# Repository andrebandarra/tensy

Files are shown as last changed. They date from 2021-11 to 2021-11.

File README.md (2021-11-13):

<h1 align="center">Tensy</h1>

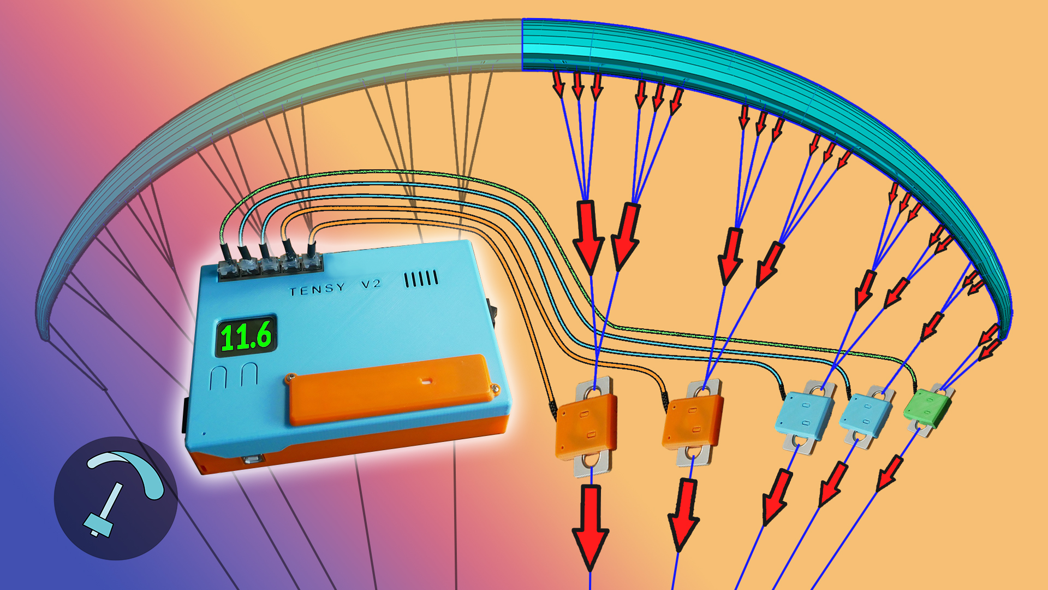
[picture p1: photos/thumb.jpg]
Table


https://www.youtube.com/watch?v=AOkSkCXVu8w --- https://andrebandarra.com/tensy
https://easyeda.com/Bandarra/line-tension-v2_copy

## Description
Wanting to measure a log loadsensor data from multiple paraglider lines in flight I've created Tensy.

It's based on an Arduino Due, the HX711 load sensor ADC and various periferals like an LCD, SD card module and various buttons.
Created a PCB for ease of wiring.

## Features
* Up to 13 load sensors
* Up to 50 kg range on each sensor
* +/- 50gram accuracy
* 10Hz sampling rate on all sensors in parallel
* 80Hz sampling rate on single sensors possible
* All data written to SD card
* LCD display for live data

[andrebandarra.com](https://andrebandarra.com/) --- [Youtube](https://www.youtube.com/channel/UCzYf1cmKwDMSiII9SSp6IJw) --- [Patreon](https://www.patreon.com/bandarra)

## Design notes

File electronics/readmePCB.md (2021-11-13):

editable pcb files on EasyEDA

https://easyeda.com/Bandarra/line-tension-v2_copy

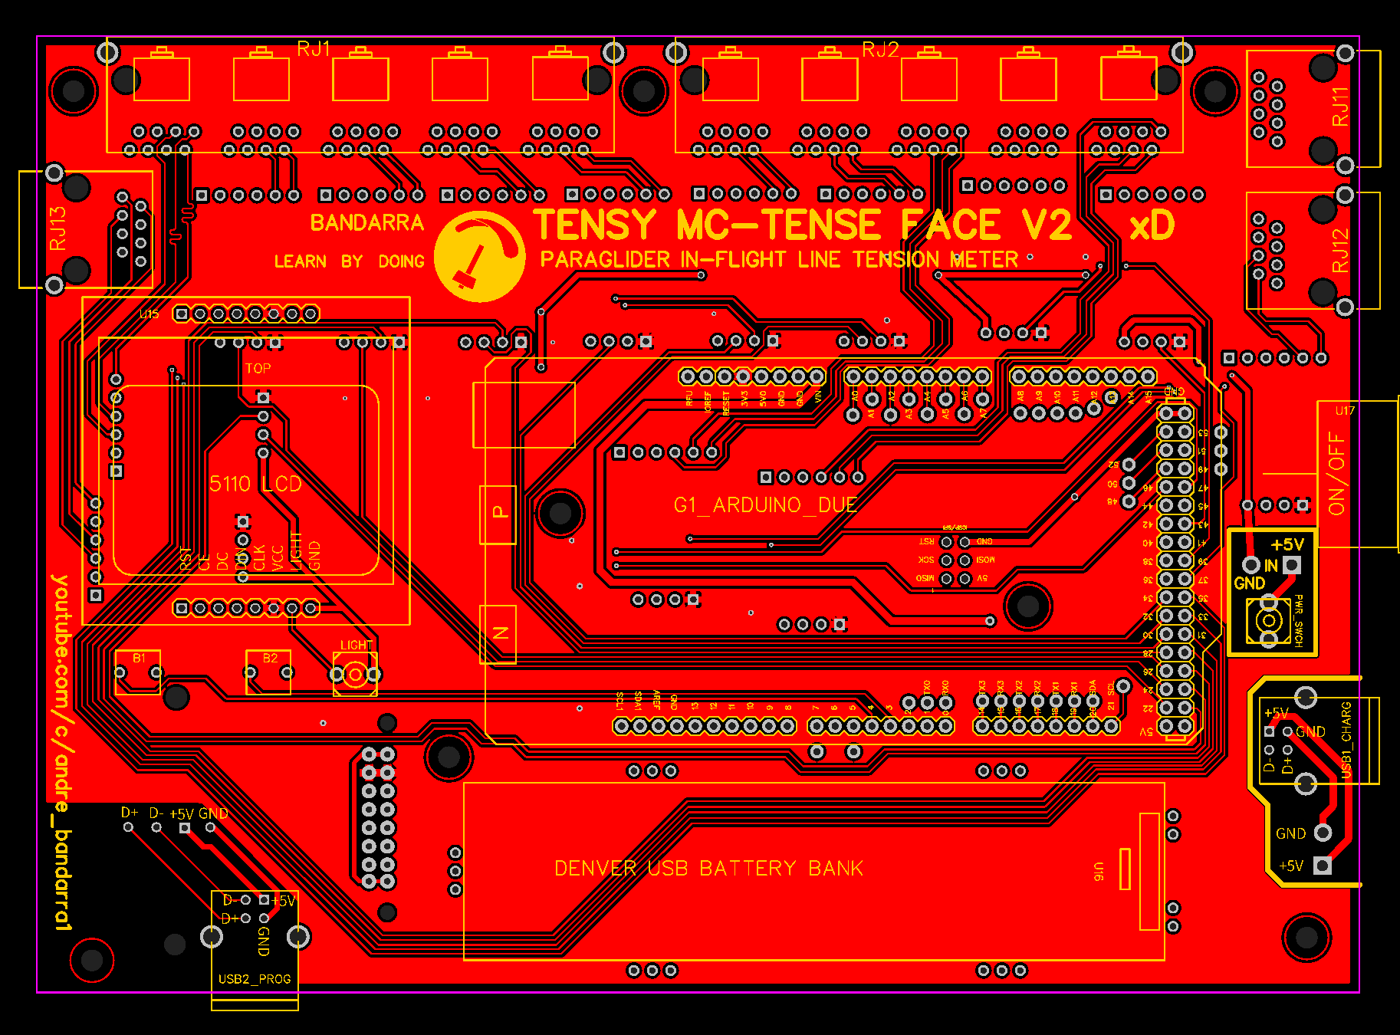
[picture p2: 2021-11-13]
electronics/schematics/PCB_Tensy Mc-Tense Face V2_20200204234458.png

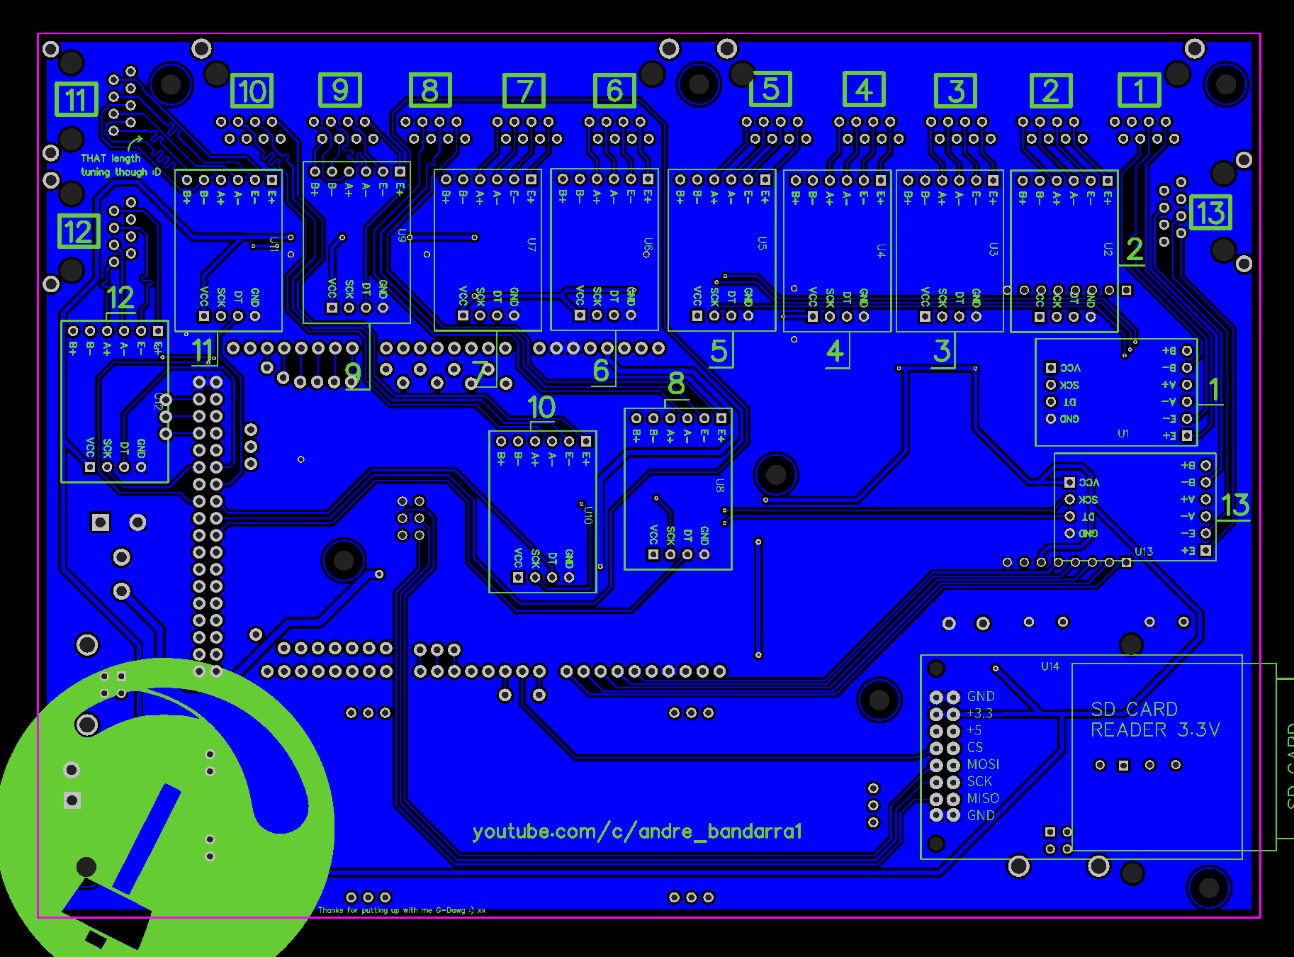
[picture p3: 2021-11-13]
electronics/schematics/PCB_Tensy Mc-Tense Face V2_20200204234511.png

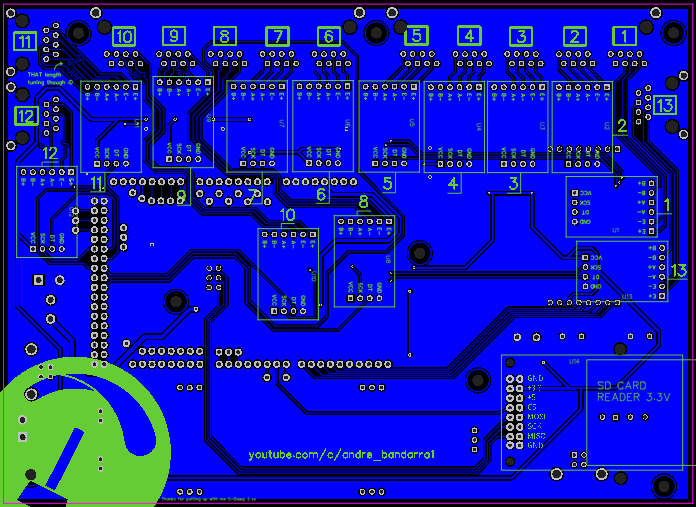
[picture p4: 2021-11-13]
cad/Tensy V2/easy eda original cad/PCB_Tensy Mc-Tense Face V2_20200315195208.png

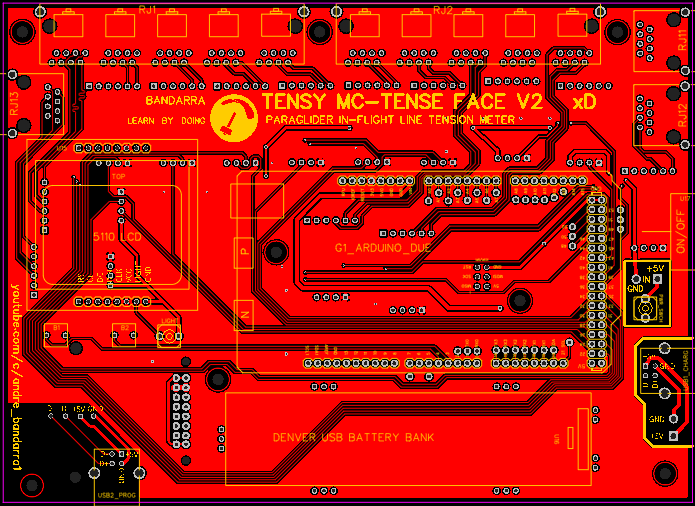
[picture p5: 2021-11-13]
cad/Tensy V2/easy eda original cad/PCB_Tensy Mc-Tense Face V2_20200315193410.png

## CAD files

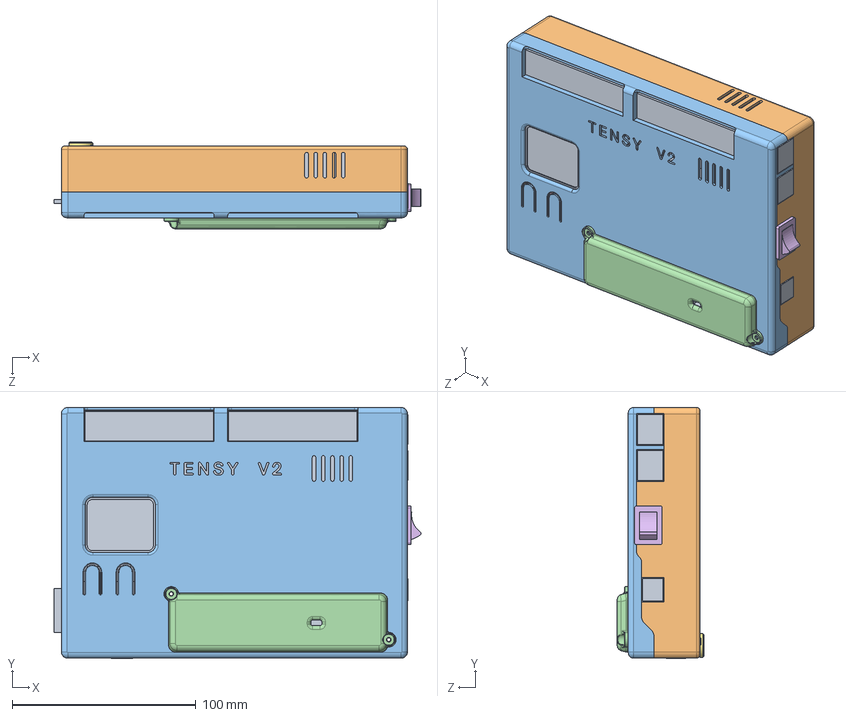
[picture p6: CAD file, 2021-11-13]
cad/Tensy V2/enclosure/Assy.SLDASM
199.9 x 136.8 x 47.2 mm
tensy final pcb
bottom
top
bat cover
sdspacer
power button
foot

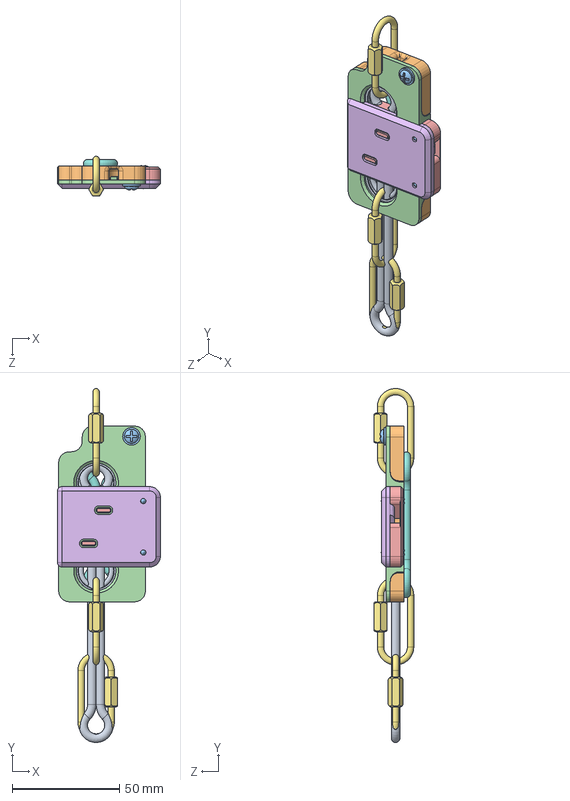
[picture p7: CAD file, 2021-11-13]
cad/sensor rigging assy/1 sensor assy.SLDASM
48.0 x 165.1 x 18.5 mm
load cell 50kg
black screw x 2
maillon35mm x 3
60mm spacer

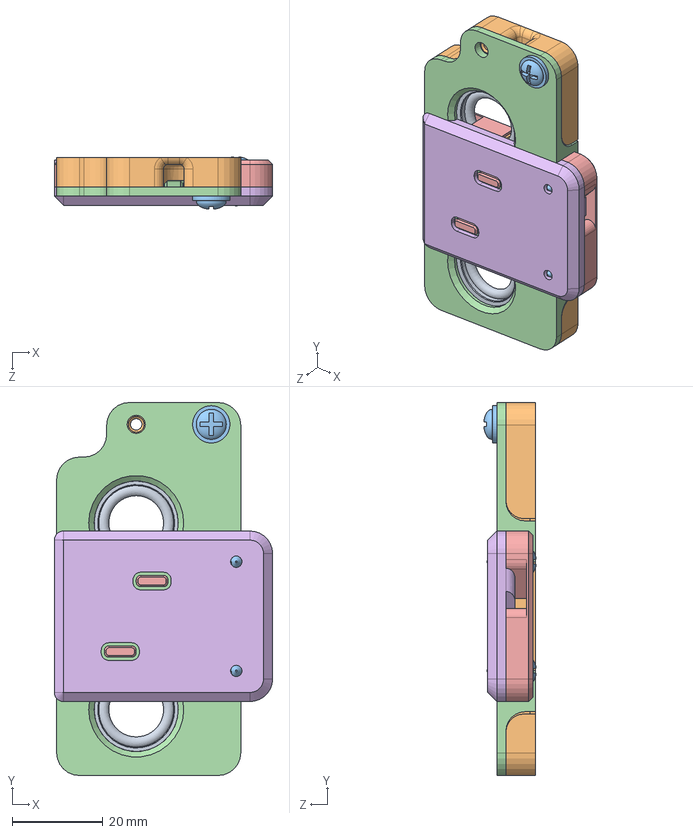
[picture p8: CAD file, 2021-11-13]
cad/Tensy V2/load cells/Assem1.SLDASM
48.0 x 82.0 x 11.5 mm
load cell 50kg
black screw x 2

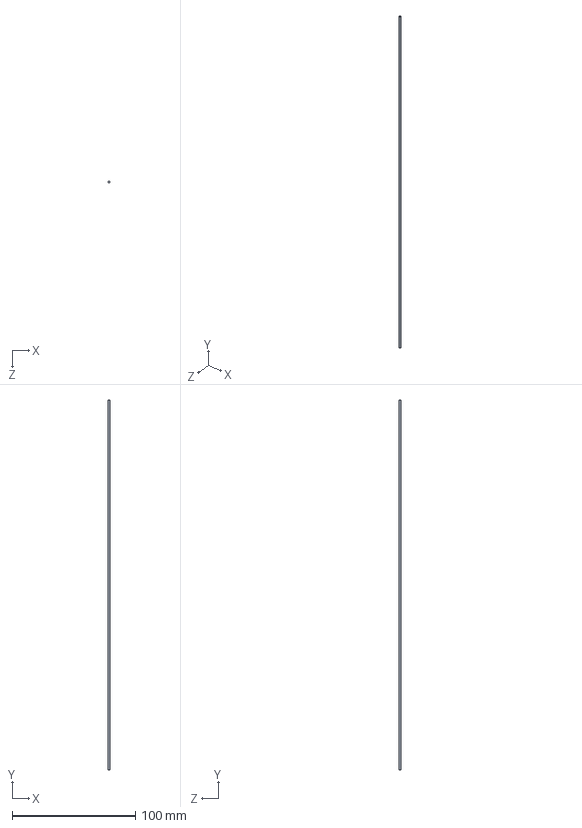
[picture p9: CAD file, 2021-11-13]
cad/riser set/1.5mm line.SLDPRT
1.50 x 300.0 x 1.50 mm

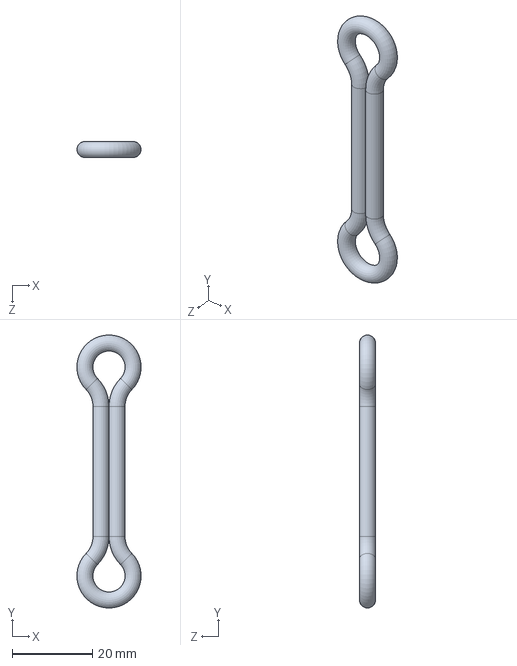
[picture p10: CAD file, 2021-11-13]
cad/sensor rigging assy/60mm spacer.SLDPRT
16.0 x 68.0 x 4.00 mm

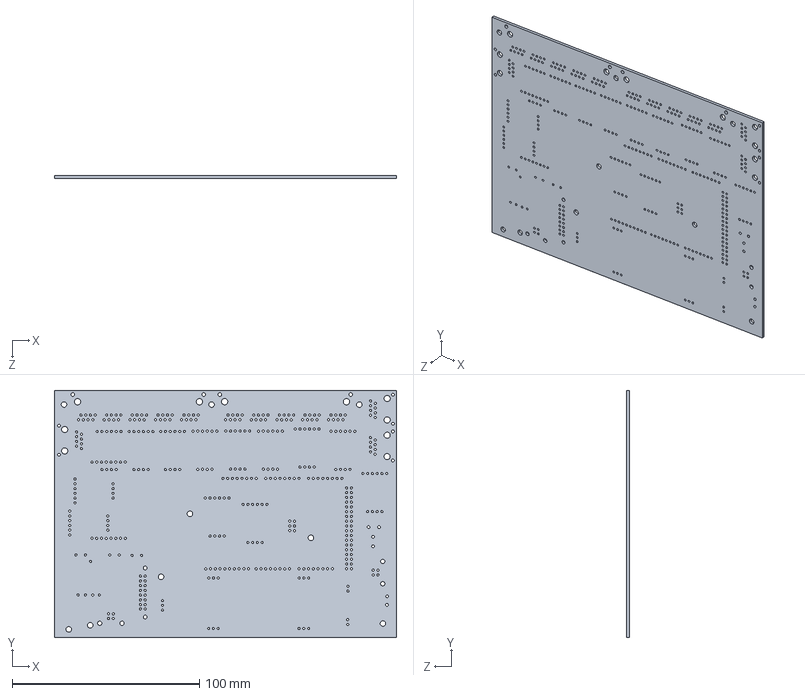
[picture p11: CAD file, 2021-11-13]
cad/Tensy V2/component test plate/test plate.SLDPRT
182.5 x 132.1 x 1.60 mm

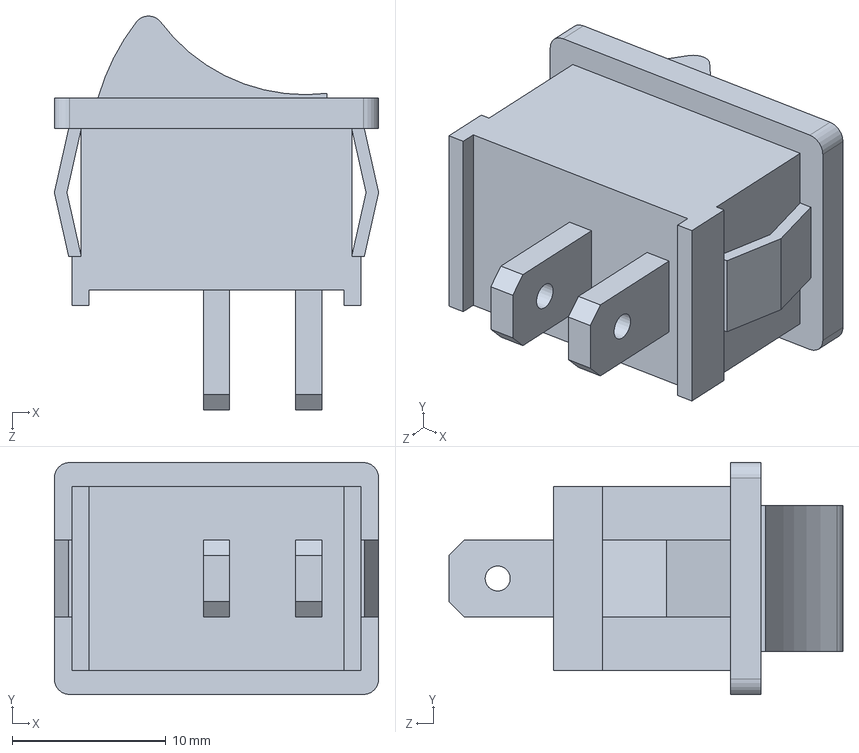
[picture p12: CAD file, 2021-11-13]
cad/Tensy V2/easy eda original cad/power button.SLDPRT
21.1 x 15.1 x 25.6 mm

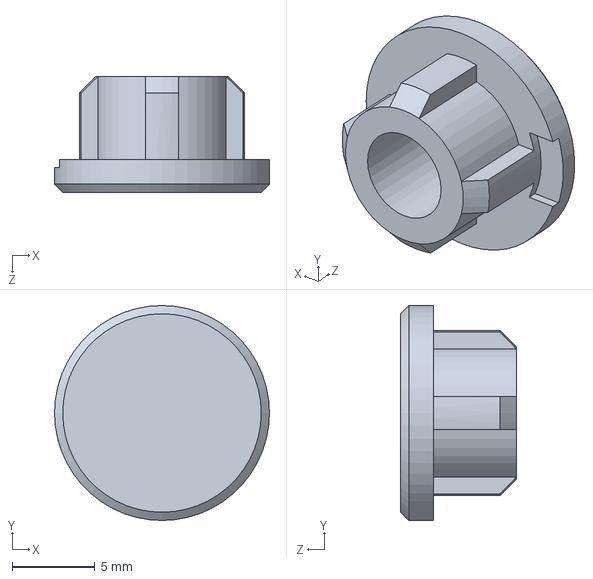
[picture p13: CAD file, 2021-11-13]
cad/Tensy V2/enclosure/foot.SLDPRT
13.0 x 13.0 x 7.00 mm

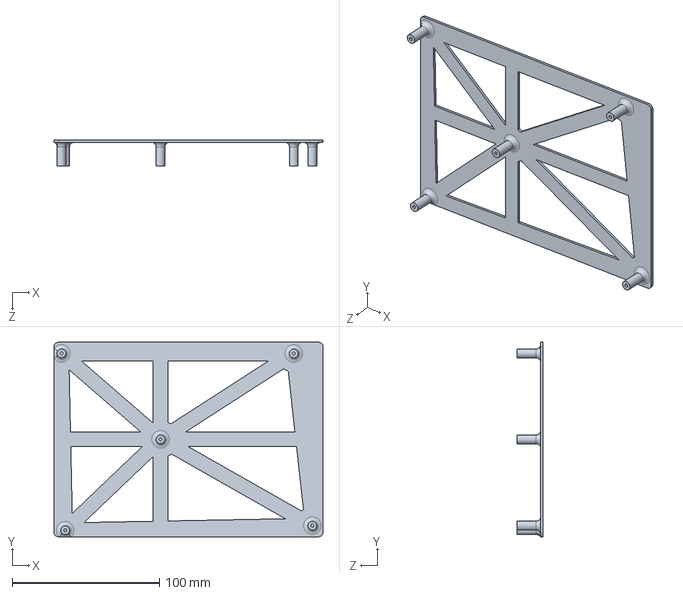
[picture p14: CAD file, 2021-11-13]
cad/Tensy V2/holder plate for prototyping/holder plate.SLDPRT
182.5 x 132.1 x 17.6 mm

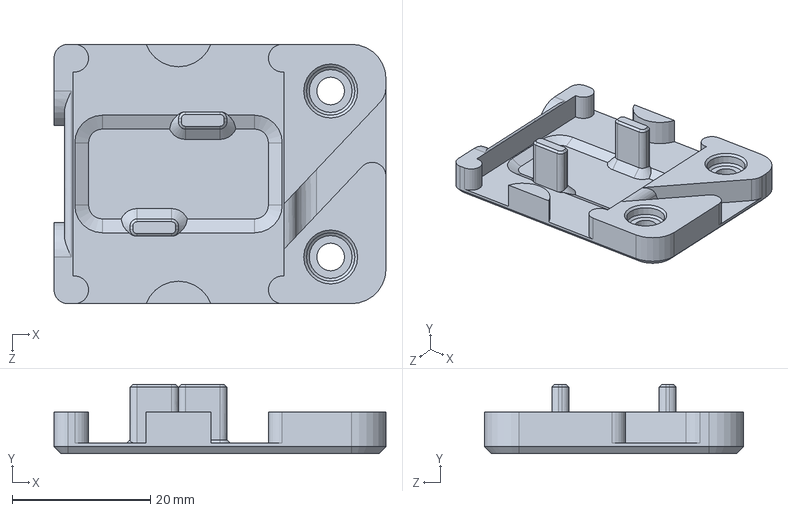
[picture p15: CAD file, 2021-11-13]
cad/Tensy V2/load cells/shell3.SLDPRT
48.0 x 10.0 x 37.5 mm

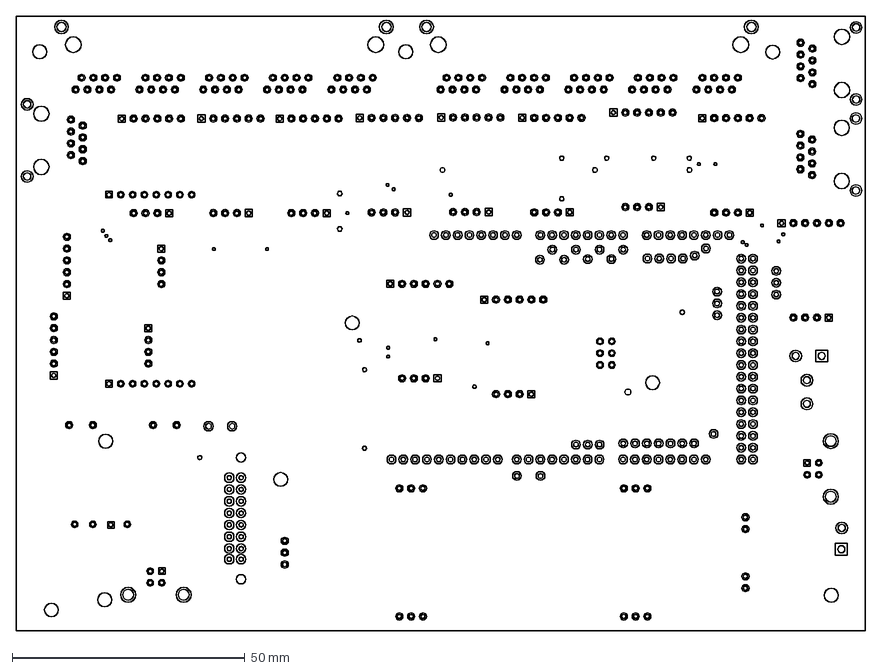
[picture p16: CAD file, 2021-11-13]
electronics/schematics/Tensy Mc-Tense Face V2.dxf
182.5 x 132.1 mm

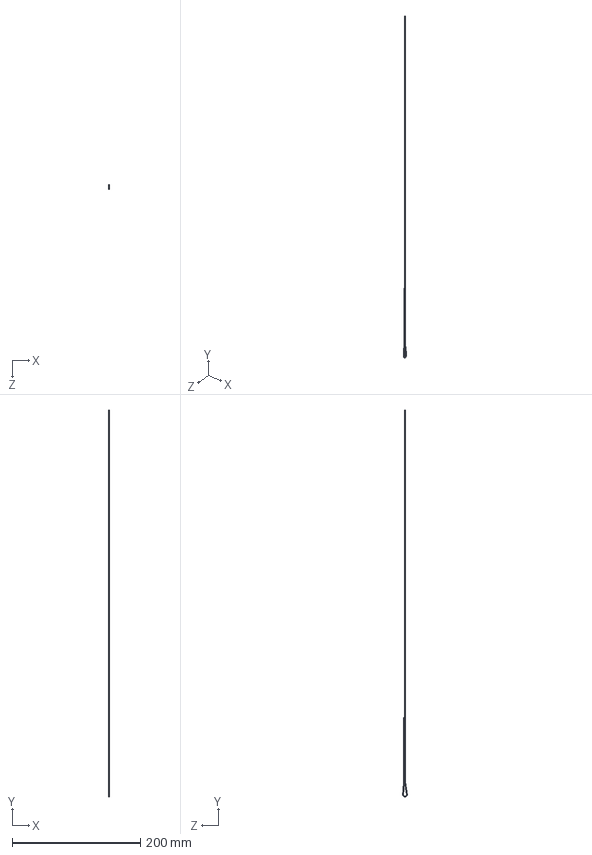
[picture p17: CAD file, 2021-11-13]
cad/riser set/B line.SLDPRT
1.50 x 603.7 x 7.47 mm

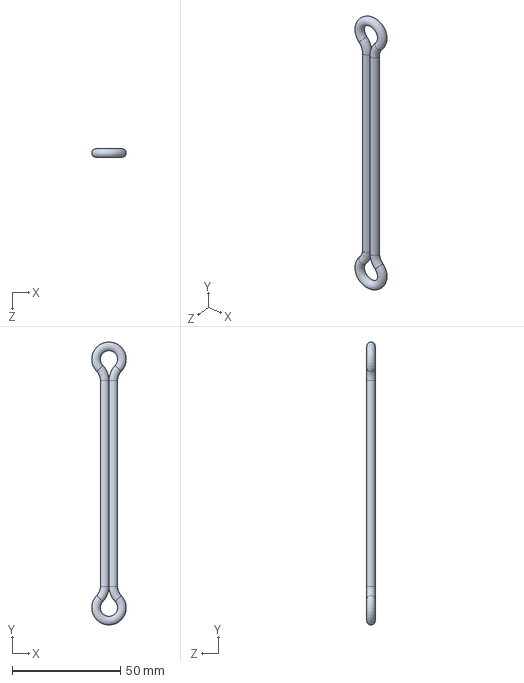
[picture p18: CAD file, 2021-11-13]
cad/sensor rigging assy/123mm spacer.SLDPRT
16.0 x 131.0 x 4.00 mm

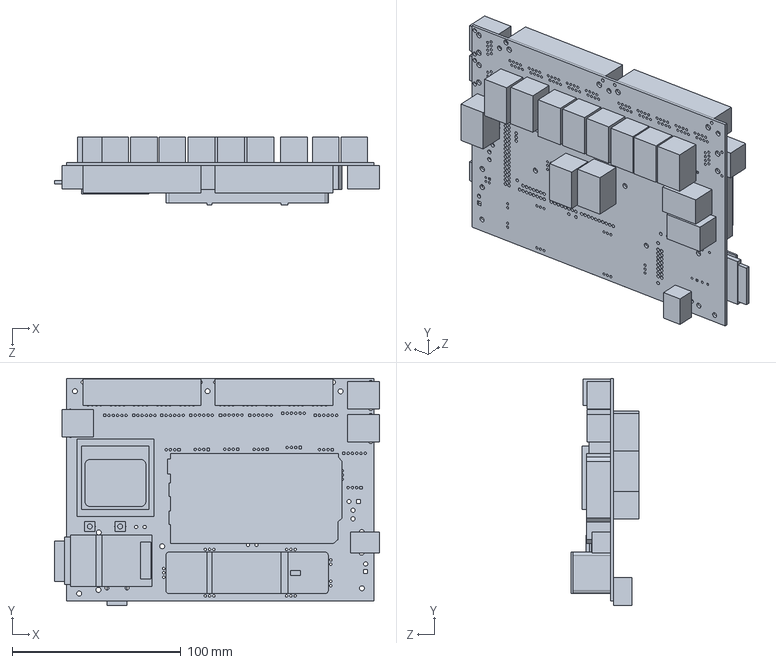
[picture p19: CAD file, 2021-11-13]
cad/Tensy V2/easy eda original cad/tensy final pcb.SLDPRT
192.7 x 134.8 x 40.2 mm

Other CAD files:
electronics/schematics/holes only Tensy Mc-Tense Face V2 .dxf
cad/riser set/maillon35mm.SLDPRT
cad/Tensy V2/easy eda original cad/Tensy Mc-Tense Face V2.dxf
cad/Tensy V2/enclosure/sdspacer.SLDPRT
cad/Tensy V2/enclosure/bat cover.SLDPRT
cad/Tensy V2/enclosure/bottom.SLDPRT
cad/Tensy V2/enclosure/foot.STL
cad/Tensy V2/enclosure/sdspacer.STL
cad/Tensy V2/enclosure/top.SLDPRT
cad/Tensy V2/holder plate for prototyping/holder plate.STL
cad/Tensy V2/load cells/black screw.SLDPRT
cad/Tensy V2/load cells/load cell 50kg.SLDPRT
cad/Tensy V2/load cells/shell1.SLDPRT
cad/Tensy V2/load cells/shell1.STL
cad/Tensy V2/load cells/shell2.SLDPRT
cad/Tensy V2/load cells/shell2.STL
cad/Tensy V2/load cells/shell3.STL
cad/Tensy V2/load cells/shell4.SLDPRT
cad/Tensy V2/load cells/shell4.STL
cad/riser set/A line.SLDPRT
cad/riser set/Brake line.SLDPRT
cad/riser set/C line.SLDPRT
cad/riser set/maillon40mm.SLDPRT
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

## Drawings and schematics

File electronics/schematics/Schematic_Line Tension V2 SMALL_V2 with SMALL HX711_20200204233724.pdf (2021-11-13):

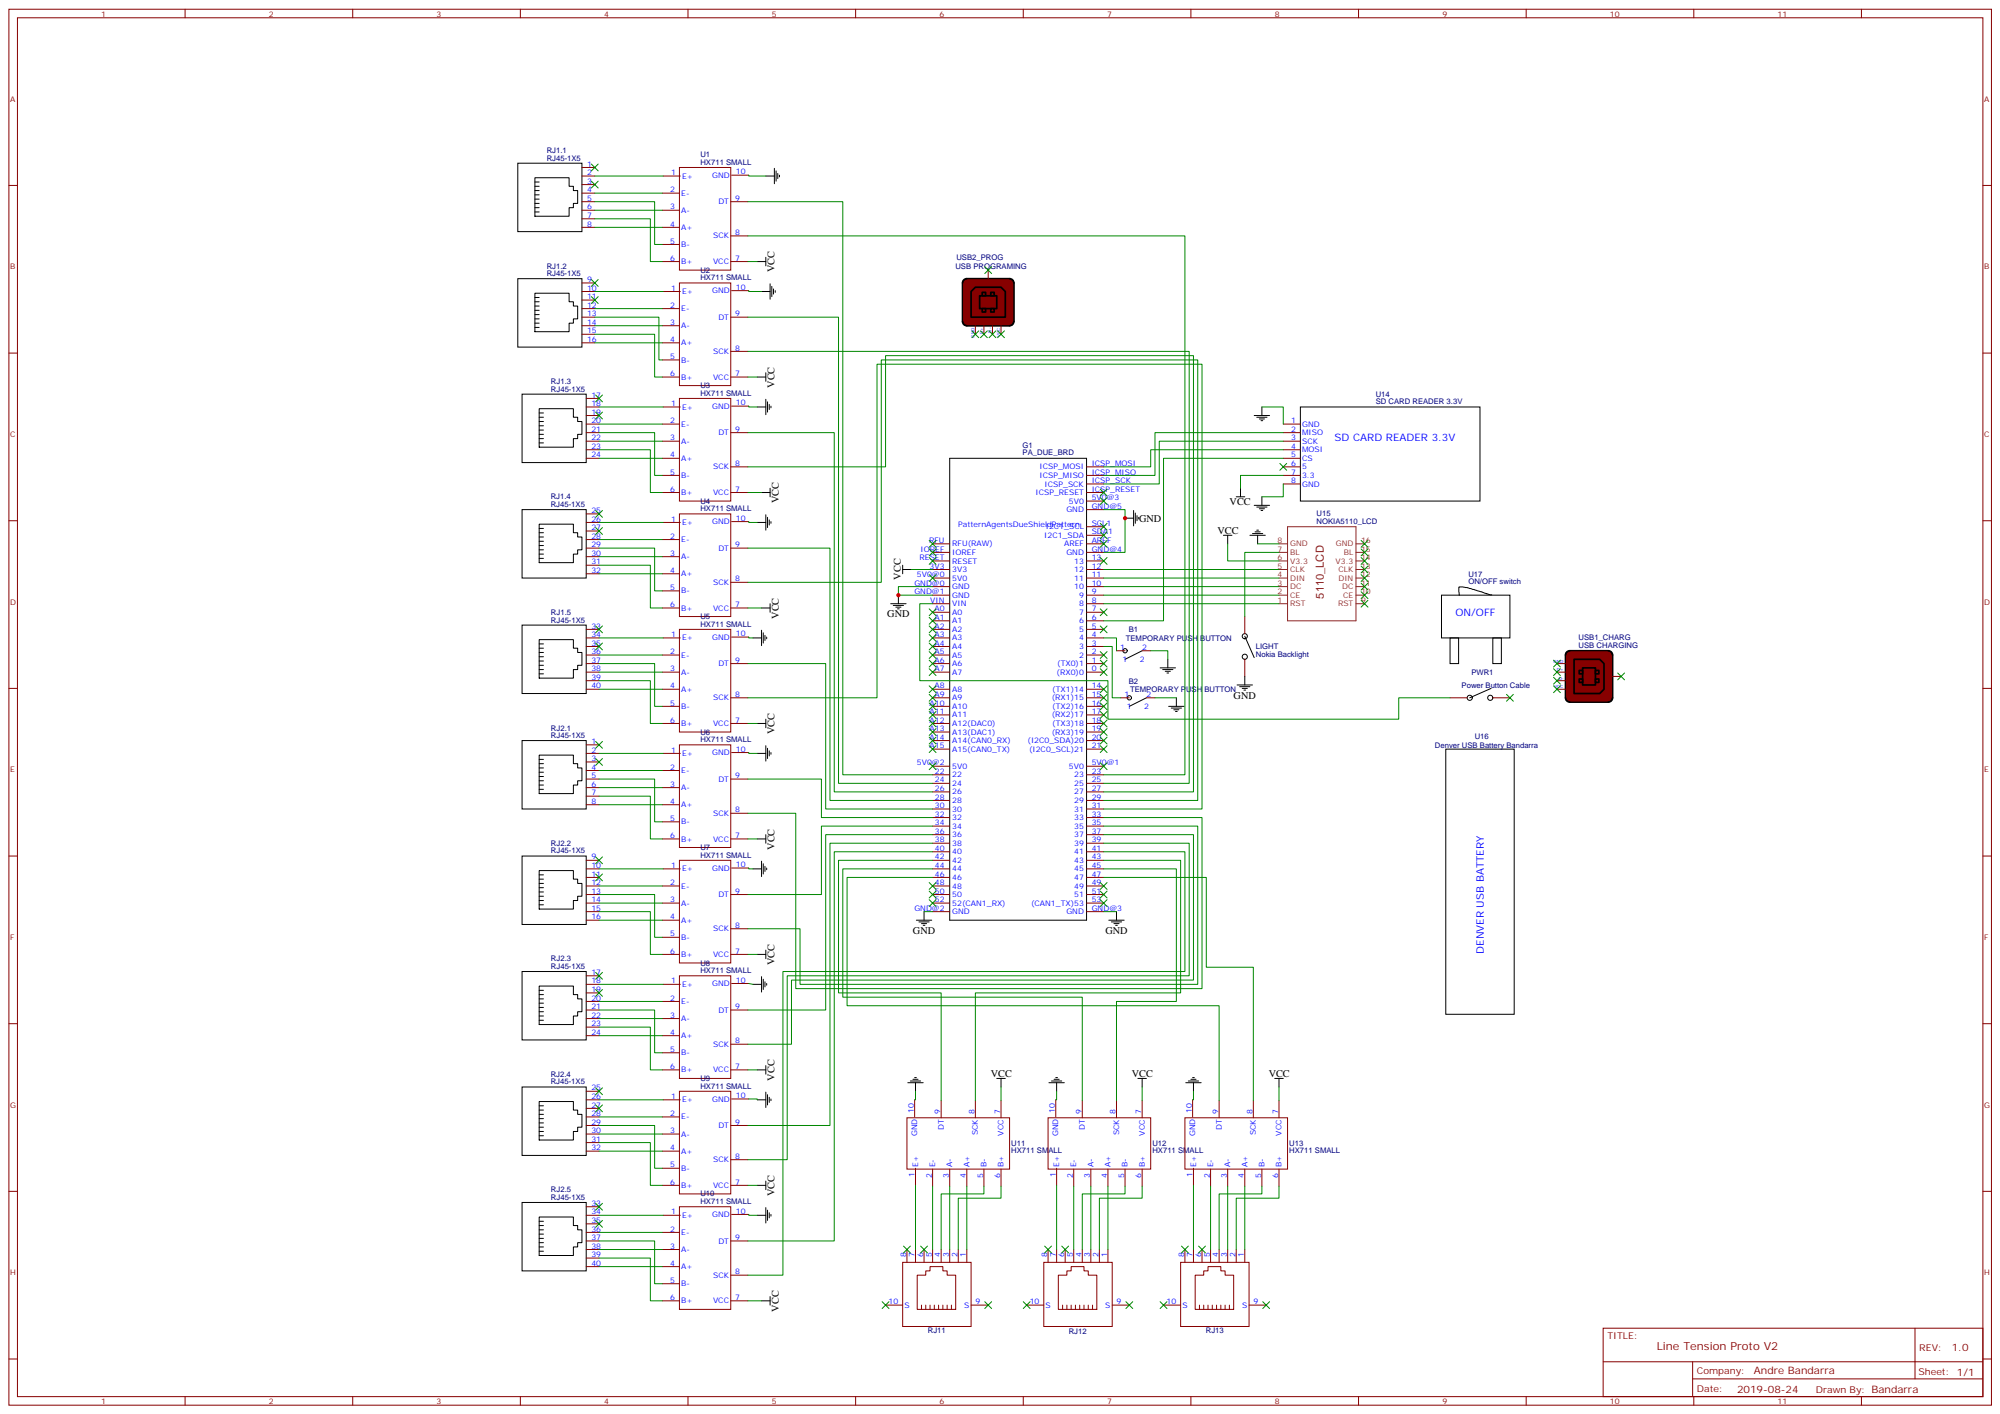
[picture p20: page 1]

VCC VCC VCC VCC VCC

10 | 3

Denver USB Battery Bandarra

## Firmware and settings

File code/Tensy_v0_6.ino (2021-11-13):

/* 
Tensy V0.6
Uses the Tensy Mc-Tense Face V2 Hardware https://easyeda.com/editor#id=8d637346f792449f84bd48fbd7bb56de
Used on the first flight test with Swift 5

Changes from V0.5
- added timer on bot left corner (right button resetable)

number of active loadcells selectable on activeScales

Setup
- Sets up LCD
- Sets up SD card, file and header
- Sets up and calibrates scales

Loop
- Keeps track of time
- Performs functions at predefined rates
  - checks buttons state
  - writes hx711 readings to readings array
  - readings array
    - print on Serial
    - write on SD
    - print on LCD
*/

// =================== Timekeeping/Scheduling ==================
unsigned long currentMillis;          //current millis
unsigned long hx711Millis = 0;        //previous millis since hx711 readings
unsigned long serialMillis = 0;       //previous millis since serial
unsigned long sdMillis = 0;           //previous millis since sd write
unsigned long lcdMillis = 0;          //previous millis since lcd update
unsigned long buttonsMillis = 0;      //previous millis since buttons check

unsigned long allSeconds;             //current millis in seconds
char timeStart[5];                    //time allSeconds in 4 characters (5-1)

unsigned long buttonSeconds;          //button seconds, allSeconds - pressSeconds
char timeButton[3];                   //time buttonSeconds in 2 characters (3-1)
unsigned long pressSeconds;           //press millis in seconds

int hx711Rate = 100;                //millis interval for taking hx711 reading
int serialRate = 500;               //millis interval for serial update
int sdRate = 100;                   //millis interval for sd card write update
int lcdRate = 500;                  //millis interval for lcd update
int buttonsRate = 200;              //millis interval for buttons update

// =================== Buttons ==================
int Lbuttonpin = 4;               //pin for Left button
int Rbuttonpin = 3;               //pin for Right button
int LBval;                        //value of Left button
int RBval;                        //value of Right button

// =================== HX711 Scales ==================
#include "HX711.h"  //HX711 library

HX711 scale[13];       //sets up X scales
byte scalePins[13][2] = {{22,23},{24,25},{26,27}, {28,29}, {30,31},{32,33},{34,35},{36,37},{38,39},{40,41},{42,43},{44,45},{46,47}};     //defines the pairs of pins for each scale
const float calib[13] = {10200, 9564, 10249, 10204, 9753, 9850, 9000, 9800, 9450, 9575, 9700, 9800, 9800};                                  //defines the calibration factor for each scale
const int activeScales = 11;
const int init_sample = 50; //initial sample size
const int mini_sample = 25;  //mini sample size
const int sec_sample = 100;  //secondary sample size
float readings[13];               //array where hx711 readings are stored
const int readingSamples = 1;     //number of samples averaged to store on readings array 

// =================== SD CARD ==================
#include <SPI.h>                  //SPI communication library
#include <SD.h>                   //SD Card library
const int sdpin = 6;              //sd Chip Select pin
File dataFile;                    //Creates logging file
char fileName[] = "LOGGER00.TXT"; //Base filename for logging
const int sdWriteSamples = 1;     //number of averaged samples to write on SD card 
bool sdIcon = false;              //icon for LCD when SD is writting 

// =================== Nokia 5110 LCD ==================
#include <LCD5110_Graph.h>        //lcd library
LCD5110 myGLCD(12,11,10,8,9);     //pins: SCK, DIN, DC, RST, CS, (ground light for on)
extern uint8_t SmallFont[];       //defines usable font 
extern uint8_t TinyFont[];        //defines usable font 
//extern uint8_t MediumNumbers[];
byte xyScales1[13][2] = {{10,10},{30,10},{50,10},{10,20},{30,20},{50,20},{70,20},{10,30},{30,30},{50,30},{10,40},{30,40},{50,40}};     //defines the pairs of X,Y coords for each of the scales print (13 SMALL)
byte xyScales2[13][2] = {{1,1},{30,1},{59,1},{1,11},{30,11},{59,11},{1,21},{30,21},{59,21},{1,31},{30,31},{59,31},{84,48}};     //defines the pairs of X,Y coords for each of the scales print (12 BIG)

void setup() {
  pinMode(Lbuttonpin, INPUT_PULLUP);     //configure pin as an input and enable the internal pull-up resistor
  pinMode(Rbuttonpin, INPUT_PULLUP);     //configure pin as an input and enable the internal pull-up resistor

  Serial.begin(57600);                      //initiate serial port
  Serial.println("Booting");
  Serial.print("Initializing LCD ");
  myGLCD.InitLCD();                         //initiate LCD
  myGLCD.setFont(SmallFont);
  myGLCD.clrScr();
  myGLCD.print("==Tensy V2==", CENTER, 2);
  myGLCD.update(); 
  Serial.println("DONE");

  delay(500);
  Serial.print("Initializing SD card  ");
  myGLCD.print("Init SD", LEFT, 11);
  myGLCD.update(); 
  if (!SD.begin(sdpin)){
    Serial.println("FAILED!");
    myGLCD.print("FAIL!", RIGHT, 11);
    myGLCD.update(); 
  }
  else{
    delay(500);
    Serial.println("DONE");
    myGLCD.print("DONE", RIGHT, 11);
    myGLCD.update(); 
  }
  for (byte i = 1; i <= 99; i++){         // Construct the filename to be the next incrementally indexed filename in the set [00-99].  
    if (SD.exists(fileName)){             // check before modifying target filename.     
      fileName[6] = i/10 + '0';           // the filename exists so increment the 2 digit filename index.
      fileName[7] = i%10 + '0';
    } 
   }
  dataFile = SD.open(fileName, FILE_WRITE);       // Open up the file we're going to log to!
  if (! dataFile){
    Serial.println("Error opening LOGGERXX.txt");
    myGLCD.print("file ERROR", CENTER, 21);
    myGLCD.update();
  }
  dataFile.println("#Tensy McTense V2 - Firmware V0.6");  //write Logger file header
  dataFile.print("#Cells calib values");                  
  for (byte j = 0; j <= activeScales; j++){              
    dataFile.print("\t");
    dataFile.print(calib[j]);
  }
  dataFile.println();
  
  dataFile.print("time");
  for (byte j = 1; j <= activeScales; j++){              
    dataFile.print(",");
    dataFile.print(j);
  }
  dataFile.println();
  
   dataFile.print("s");
  for (byte j = 1; j <= activeScales; j++){              
    dataFile.print(",");
    dataFile.print("kg");
  }
  dataFile.println();

    myGLCD.print("Calib Scales", CENTER, 40);
    myGLCD.update();
   
  for (int ida = 0; ida < activeScales; ida++){
    scale[ida].begin(scalePins[ida][0], scalePins[ida][1]);   //initializes each of the scales using the pin pairs
    scale[ida].set_gain(64);                                  //sets the gain for each of the scales
    Serial.print("Calibrating Scale ");
    Serial.print(ida+1);
    myGLCD.invertText(false);                   //gets text back to normal
    myGLCD.printNumI(ida+1,ida*6+1, 31);        //prints scale number on LCD and increments X spacing
    myGLCD.update();
    scale[ida].read();                          //raw reading from the ADC
    scale[ida].read_average(init_sample);       //average of X readings from the ADC
    scale[ida].get_value(mini_sample);          //average of Y readings from the ADC minus the tare weight (not set yet)
    scale[ida].get_units(mini_sample);          //average of Y readings from the ADC minus tare weight (not set) divided by the SCALE parameter (not set yet)
    scale[ida].set_scale(calib[ida]);           //set scale calibration factor
    scale[ida].tare();                          //reset the scale to 0
    scale[ida].read();                          //raw reading from the ADC 
    scale[ida].read_average(sec_sample);        //average of Z readings from the ADC
    scale[ida].get_value(mini_sample);          //average of Y readings from the ADC minus the tare weight, set with tare()
    scale[ida].get_units(mini_sample);          //average of Y readings from the ADC minus tare weight, divided by the SCALE parameter set with set_scale
    scale[ida].tare();                          //reset the scale to 0
    Serial.println(" DONE");
    myGLCD.invertText(true);                    //inverts text as confirmation
    myGLCD.printNumI(ida+1,ida*6+1, 31);        //prints scale number on LCD and increments X spacing
    myGLCD.invertText(false);                   //gets text back to normal
    myGLCD.update();
  }
}

void buttons_check(){
  if (currentMillis - buttonsMillis > buttonsRate){       //checks if enough time has gone past to update
  
  LBval = digitalRead(Lbuttonpin);                        //read the pushbutton value into the variable
  RBval = digitalRead(Rbuttonpin);                        //read the pushbutton value into the variable

    if (RBval == LOW){
      pressSeconds = millis()/1000;      
      }

   
   buttonsMillis = currentMillis;                          //records when was the last time it was updated
  }
}

void hx711_Update(){
  if (currentMillis - hx711Millis > hx711Rate){                    //checks if enough time has gone past to update
    for (int idb = 0; idb < activeScales; idb++){
      readings[idb] = (scale[idb].get_units(readingSamples));      //prints each scale to serial, with X decimal places
    } 
   hx711Millis = currentMillis;                                    //records when was the last time readings were updated
  }
}

void tension_printSerial() {
  if (currentMillis - serialMillis > serialRate){     //checks if enough time has gone past to update
   Serial.print(millis()/1000.0, 1);                       //prints seconds to serial
    for (int idc = 0; idc < activeScales; idc++){
      Serial.print("\t");
      Serial.print(readings[idc], 3);                 //prints value of the readings array to serial, with X decimal places
    }
   Serial.println();
   serialMillis = currentMillis;                       //records when was the last time readings were updated
  }
}

void tension_writeSD() {
  if (currentMillis - sdMillis > sdRate){             //checks if enough time has gone past to update
   dataFile.print(millis()/1000.0, 1);                     //prints seconds to sd, with 1 decimal place
    for (int idd = 0; idd < activeScales; idd++){
      dataFile.print(",");
      dataFile.print(readings[idd], 3);           //prints each scale to sd, with X decimal places
    }
   dataFile.println();
   dataFile.flush();                              //save after every line of data. Safer but slower
   sdMillis = currentMillis;                      //records when was the last time readings were updated
   if (SD.exists(fileName)){
    sdIcon = true;
   }
  }
}

void print_LCD() {
  if (currentMillis - lcdMillis > lcdRate){                       //checks if enough time has gone past to update
    myGLCD.clrScr();

    for (int idf = 0; idf < activeScales; idf++){
      myGLCD.printNumF(readings[idf],1,xyScales2[idf][0],xyScales2[idf][1]);      //prints each scale to LCD, with W decimal placesplaces, in position X and Y
    }

    allSeconds = millis() / 1000;                       //updates timer
    sprintf(timeStart, "%04d", allSeconds);
    myGLCD.print(timeStart, 0, 41);                      //prints total time to bot left
    buttonSeconds = allSeconds - pressSeconds;
    sprintf(timeButton, "%02d", buttonSeconds);
    myGLCD.print(timeButton, 30, 41);                    //prints button time to bot centre
    myGLCD.update();
    
     if (sdIcon == true){                                //if tension_writeSD is running and card and file are initialized this is true
      myGLCD.invertText(true);
      myGLCD.print("SD ON", 54,41);
      myGLCD.update();
      myGLCD.invertText(false);
      sdIcon = false; 
    }
    else{
      myGLCD.print("SD OFF", 49,41); 
      myGLCD.update();      
    }
 
   lcdMillis = currentMillis;                       //records when was the last time readings were updated
  } 
}

void loop() {
currentMillis = millis();                           //updates timekeeping
buttons_check();                                    //checks buttons statuses
hx711_Update();                                     //reads and stores hx711 readings
tension_printSerial();                              //prints readings to serial
tension_writeSD();                                  //writes tensions to SD
print_LCD();                                        //prints to LCD version two (12 BIG)
}
